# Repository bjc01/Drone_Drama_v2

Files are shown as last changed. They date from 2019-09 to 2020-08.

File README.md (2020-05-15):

# Drone_Drama_v2
DIY electronic musical Instrument

Drone & Drama v2 is a DIY synthesizer.

The complete unit contains the following:

3x sine / triangle function generators.

noise siren (a "bent by design" dub siren)

filter (a "bent by design" envelope filter)

4 channel mixer

The instrument is best suited to slow, drone and/or noise / music

Test commit

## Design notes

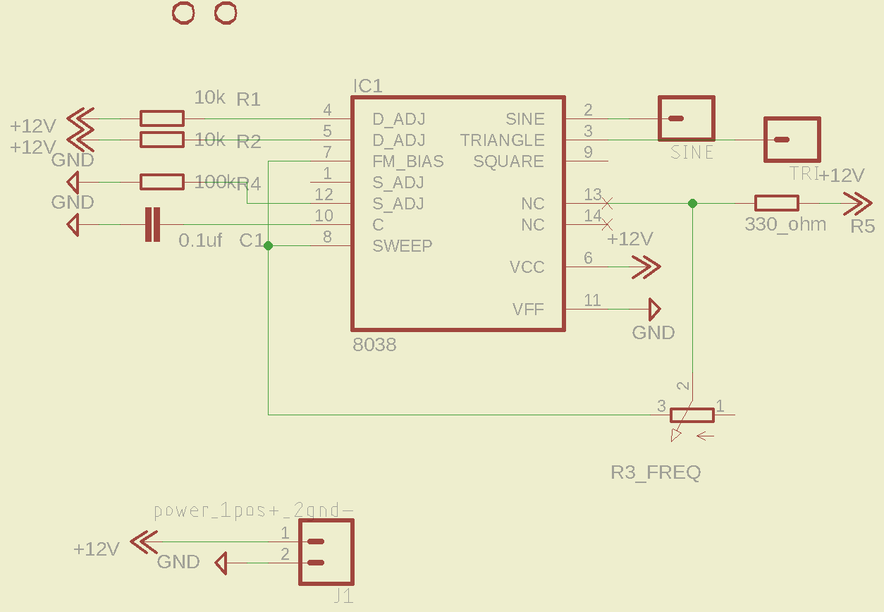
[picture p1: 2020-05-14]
D&Dv2 schematics/D&Dv2_sine_tri_12v.png

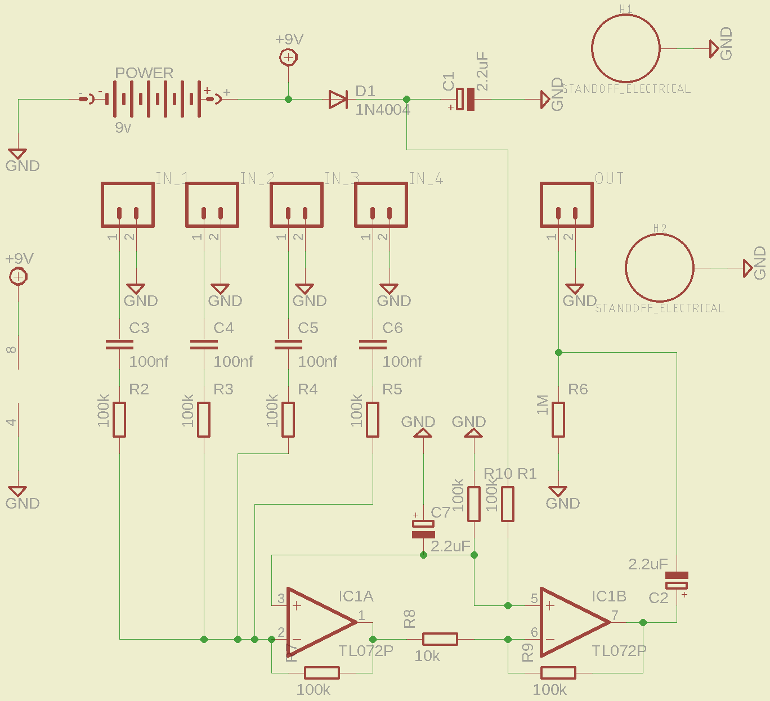
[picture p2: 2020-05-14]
D&Dv2 schematics/D&Dv2_4ch_mixer.png

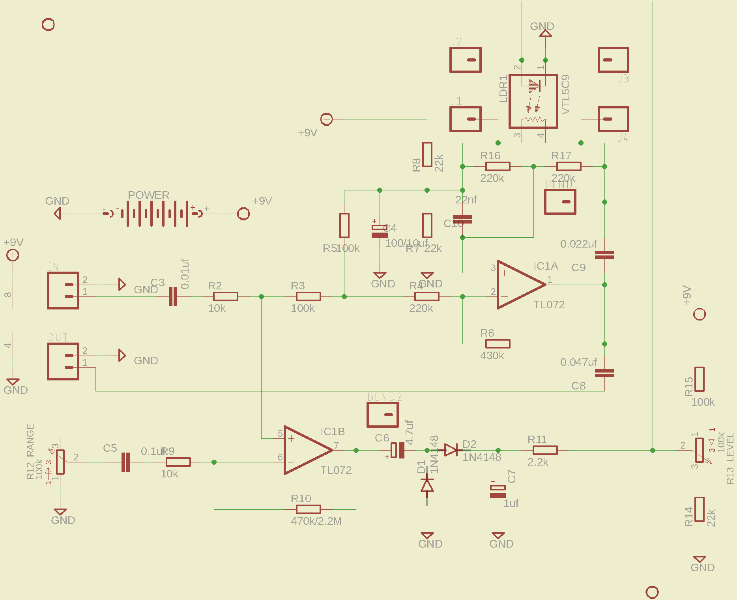
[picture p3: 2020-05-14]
D&Dv2 schematics/D&Dv2 filter.png

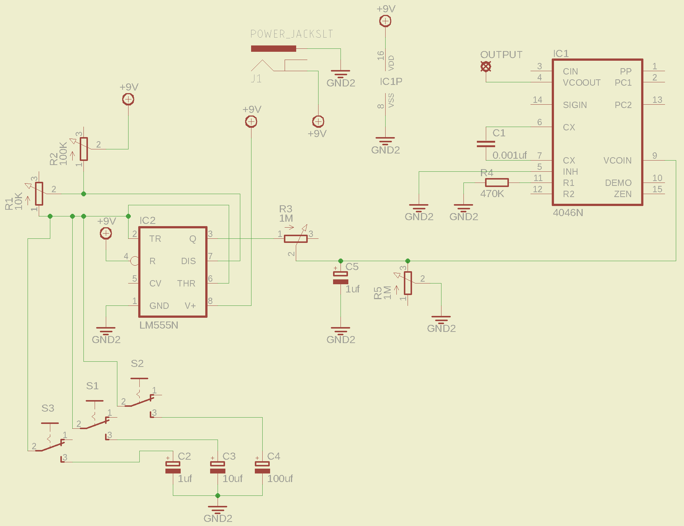
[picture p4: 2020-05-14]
D&Dv2 schematics/D&Dv2_noise_siren.png

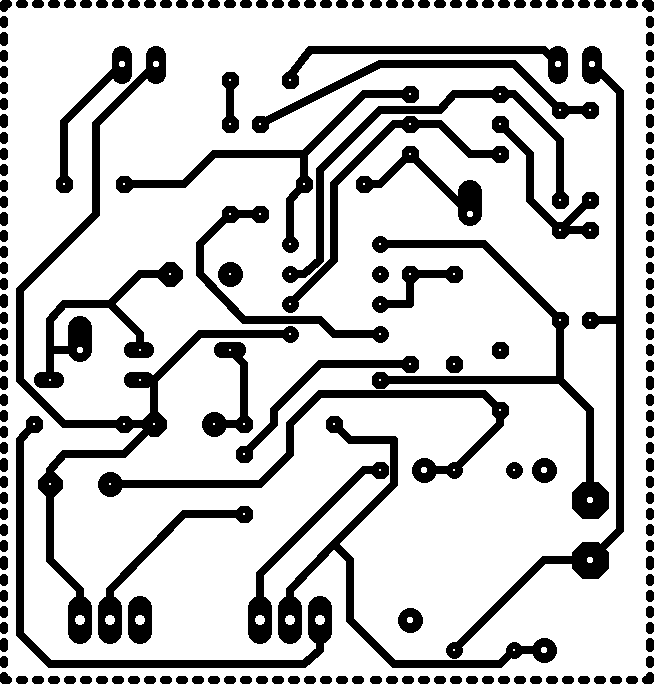
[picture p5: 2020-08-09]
D&Dv2 etch/filter etch top.png

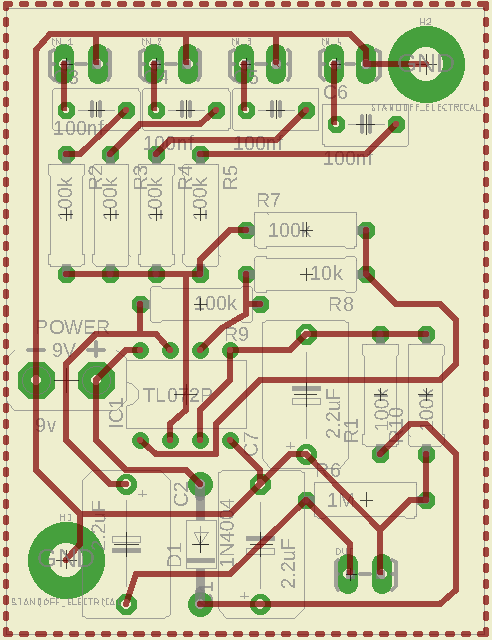
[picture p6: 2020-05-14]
D&Dv2 layout/D&Dv2_mixer_PCB1.png

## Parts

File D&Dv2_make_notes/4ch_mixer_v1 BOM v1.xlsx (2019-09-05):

4ch_mixer_v1 BOM
Part | Value | Device | Package | Description
C1 | 2.2uF | CPOL-EUB45181C | B45181C | POLARIZED CAPACITOR
C2 | 2.2uF | CPOL-EUB45181C | B45181C | POLARIZED CAPACITOR
C3 | 100nf | C-EU050-035X075 | C050-035X075 | CAPACITOR
C4 | 100nf | C-EU050-035X075 | C050-035X075 | CAPACITOR
C5 | 100nf | C-EU050-035X075 | C050-035X075 | CAPACITOR
C6 | 100nf | C-EU050-035X075 | C050-035X075 | CAPACITOR
C7 | 2.2uF | CPOL-EUB45181C | B45181C | POLARIZED CAPACITOR
D1 | 1N4004 | 1N4004 | DO41-10 | DIODE
IC1 | TL072P | TL072P | DIL08 | OP AMP
IN_1 | Audio input | CONN_02LOCK_LONGPADS | 1X02_LOCK_LONGPADS | Multi connection point. + / -
IN_2 | Audio input | CONN_02LOCK_LONGPADS | 1X02_LOCK_LONGPADS | Multi connection point. + / -
IN_3 | Audio input | CONN_02LOCK_LONGPADS | 1X02_LOCK_LONGPADS | Multi connection point. + / -
IN_4 | Audio input | CONN_02LOCK_LONGPADS | 1X02_LOCK_LONGPADS | Multi connection point. + / -
OUT | Audio output | CONN_02LOCK_LONGPADS | 1X02_LOCK_LONGPADS | Multi connection point. + / -
POWER | 12v power input +/- |  |  | 12v power input +/-
R1 | 100k | R-EU_0309/10 | 0309/10 | RESISTOR
R2 | 100k | R-EU_0309/10 | 0309/10 | RESISTOR
R3 | 100k | R-EU_0309/10 | 0309/10 | RESISTOR
R4 | 100k | R-EU_0309/10 | 0309/10 | RESISTOR
R5 | 100k | R-EU_0309/10 | 0309/10 | RESISTOR
R6 | 1M | R-EU_0309/10 | 0309/10 | RESISTOR
R7 | 100k | R-EU_0309/10 | 0309/10 | RESISTOR
R8 | 10k | R-EU_0309/10 | 0309/10 | RESISTOR
R9 | 100k | R-EU_0309/10 | 0309/10 | RESISTOR
R10 | 100k | R-EU_0309/10 | 0309/10 | RESISTOR
J1 | Audio output jack |  |  | 6.35mm mono output jack
use sockets for ICs!
Audio output jack EG: https://www.ebay.co.uk/itm/6-35mm-GUITAR-Jack-MONO-Socket-PCB-Mounting-Connections-Ends-AMP-Panel-Board-etc/392060661821

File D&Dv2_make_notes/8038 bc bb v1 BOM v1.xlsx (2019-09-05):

8038 bc bb v1 BOM
Part | Value | Device | Package | Description
C1 | 0.1uf |  |  | CAPACITOR - change this for change in frequency range
IC1 |  | ICL8038 | DIL14 | Precision WAVEFORM GENERATOR - https://www.ebay.co.uk/sch/i.html?_odkw=10-turn+pot+bournes+5k&_osacat=0&_from=R40&_nkw=icl8038&_sacat=0
J1 | 12v power pads +/- |  |  | 12v power pads +/-
R1 | 10k | R-EU_0204/5 | 0204/5 | RESISTOR
R2 | 10k | R-EU_0204/5 | 0204/5 | RESISTOR
R4 | 100k | R-EU_0204/5 | 0204/5 | RESISTOR
R5 | 330_ohm | R-EU_0204/5 | 0204/5 | RESISTOR
SINE | output pad | CONN_01PTH_LONGPAD | 1X01_LONGPAD | Sine wave output to toggle switch
TRI | output pad | CONN_01PTH_LONGPAD | 1X01_LONGPAD | Triangle wave output to toggle switch
R3 | 5k pot | frequency | 10-turn potentiometer | https://www.ebay.co.uk/sch/i.html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
Volume | 100k pot | volume | standard potentiometer | potentiometer 16mm / panel mount - https://www.ebay.co.uk/sch/i.html?_odkw=100k+pot&_osacat=0&_from=R40&_nkw=100k+pot+16mm&_sacat=0
Switch | SPDT toggle switch | waveform select sin/tri | two way / three pins | toggle switch - https://www.ebay.co.uk/sch/i.html?_odkw=icl8038&_osacat=0&_from=R40&_nkw=spdt&_sacat=0
Diode | zener diode | 1N4148 | standard diode | diode - https://www.ebay.co.uk/sch/i.html?_odkw=100k+pot+16mm&_osacat=0&_from=R40&_nkw=1n4148&_sacat=0
NB - for a full Drone & Drama v2 all of the above is needed three times - the above is for only enough to populate one drone PCB
use sockets for ICs!
A DC power socket (2.1mm panel mount wired tip negative) is useful to connect to a vero power board

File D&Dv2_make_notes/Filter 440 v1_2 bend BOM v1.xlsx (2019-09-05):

Filter 440 v1_2 bend BOM
Part | Value | Device | Package | Description
BEND1 | bend point | CONN_01OFFSET | 1X01_OFFSET | Single connection point.
BEND2 | bend point | CONN_01OFFSET | 1X01_OFFSET | Single connection point.
C3 | 0.01uf | C-EU050-035X075 | C050-035X075 | CAPACITOR
C4 | 100/10uf | CPOL-EUE5-6 | E5-6 | POLARIZED CAPACITOR, European symbol
C5 | 0.1uf | C-EU050-035X075 | C050-035X075 | CAPACITOR
C6 | 4.7uf | CPOL-EUE5-6 | E5-6 | POLARIZED CAPACITOR, European symbol
C7 | 1uf | CPOL-EUE5-6 | E5-6 | POLARIZED CAPACITOR, European symbol
C8 | 0.047uf | C-EU050-035X075 | C050-035X075 | CAPACITOR
C9 | 0.022uf | C-EU050-035X075 | C050-035X075 | CAPACITOR
C10 | 22nf | C-EU050-035X075 | C050-035X075 | CAPACITOR
D1 | 1N4148 | 1N4148DO35-7 | DO35-7 | DIODE
D2 | 1N4148 | 1N4148DO35-7 | DO35-7 | DIODE
IC1 | TL072 | TL072P | DIL08 | OP AMP
IN | Audio input | CONN_02LOCK_LONGPADS | 1X02_LOCK_LONGPADS | Multi connection point.
J1 | bend point | CONN_01 | 1X01 | Single connection point.
J2 | bend point | CONN_01 | 1X01 | Single connection point.
J3 | bend point | CONN_01 | 1X01 | Single connection point.
J4 | bend point | CONN_01 | 1X01 | Single connection point.
LDR1 | VTL5C9 | VTL5C9 | VTL5C | Axial Vactrols.
OUT | audio output | CONN_02LOCK_LONGPADS | 1X02_LOCK_LONGPADS | Multi connection point. Audio output +/-
POWER | 12v power +/- |  |  | 12v power +/-
R2 | 10k | R-EU_0207/7 | 0207/7 | RESISTOR
R3 | 100k | R-EU_0207/7 | 0207/7 | RESISTOR
R4 | 220k | R-EU_0207/7 | 0207/7 | RESISTOR
R5 | 100k | R-EU_0207/7 | 0207/7 | RESISTOR
R6 | 430k | R-EU_0207/7 | 0207/7 | RESISTOR
R7 | 22k | R-EU_0207/7 | 0207/7 | RESISTOR
R8 | 22k | R-EU_0207/7 | 0207/7 | RESISTOR
R9 | 10k | R-EU_0207/7 | 0207/7 | RESISTOR
R10 | 470k/2.2M | R-EU_0207/7 | 0207/7 | RESISTOR
R11 | 2.2k | R-EU_0207/7 | 0207/7 | RESISTOR
R12_RANGE | 100k | 308/309 | standard potentiomter | POTENTIOMETER
R13_LEVEL | 100k | 308/309 | standard potentiomter | POTENTIOMETER
R14 | 22k | R-EU_0207/7 | 0207/7 | RESISTOR
R15 | 100k | R-EU_0207/7 | 0207/7 | RESISTOR
R16 | 220k | R-EU_0207/7 | 0207/7 | RESISTOR
R17 | 220k | R-EU_0207/7 | 0207/7 | RESISTOR
Switch | SPDT toggle switcch | bend noise on/off | two way / three pins | toggle switch to connect bend points on PCB
Volume | A 100k |  | standard potentiomter | POTENTIOMETER
Power Starve | A 5k |  | standard potentiomter | POTENTIOMETER
NB - use sockets for ICs when possible!
DIY LDR+LED vactrol alternative: see stage 3 - https://www.instructables.com/id/Fizzle-Loop-Synth-V3/
toggle switch - https://www.ebay.co.uk/sch/i.html?_odkw=icl8038&_osacat=0&_from=R40&_nkw=spdt&_sacat=0

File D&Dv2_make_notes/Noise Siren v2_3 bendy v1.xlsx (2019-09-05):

Noise Siren v2_3 bendy
Part | Value | Device | Package | Description
C1 | 10uF | CPOL-EUB45181B | B45181B | POLARIZED CAPACITOR
C2 | 1uF | CPOL-EUB45181B | B45181B | POLARIZED CAPACITOR
C3 | 0.001uF | CPOL-EUB45181B | B45181B | POLARIZED CAPACITOR
C4 | 100uF | CPOL-EUB45181B | B45181B | POLARIZED CAPACITOR
G1 | 12v power + / - |  |  | 12v power + / -
IC1 | 555 | 555P | DIP08 | General purpose bipolar Timer
IC2 | 4046N | 4046N | DIL16 | Micropower PLL - phase locked loop
OUTPUT | Audio output to filter input | CONN_02LOCK_LONGPADS | 1X02_LOCK_LONGPADS | Multi connection point. Audio + / -
R1 | 1M | R-EU_0207/10 | 0207/10 | RESISTOR
R2 | 1M | R-EU_0207/10 | 0207/10 | RESISTOR
R3 | 470k | R-EU_0207/10 | 0207/10 | RESISTOR
S1 | SPDT toggle switch | M9040P | two position / three pin | TOGGLE SWITCH
S2 | SPDT toggle switch | M9040P | two position / three pin | TOGGLE SWITCH
S3 | SPDT toggle switch | M9040P | two position / three pin | TOGGLE SWITCH
VR1 | 100k | POTENTIOMETER-PTH-9MM-1/20W-20%-KIT | POT-PTH-ALPS-KIT | Potentiometer (Pot)
VR2 | 10k | POTENTIOMETER-PTH-9MM-1/20W-20%-KIT | POT-PTH-ALPS-KIT | Potentiometer (Pot)
VR3 | 10k | POTENTIOMETER-PTH-9MM-1/20W-20%-KIT | POT-PTH-ALPS-KIT | Potentiometer (Pot)
VR4 | 1k | POTENTIOMETER-PTH-9MM-1/20W-20%-KIT | POT-PTH-ALPS-KIT | Potentiometer (Pot)
bends | 6pcs banan jacks | banana jacks |  | 6 pieces - Banana jacks for bend points
NB - use sockets for ICs when possible!

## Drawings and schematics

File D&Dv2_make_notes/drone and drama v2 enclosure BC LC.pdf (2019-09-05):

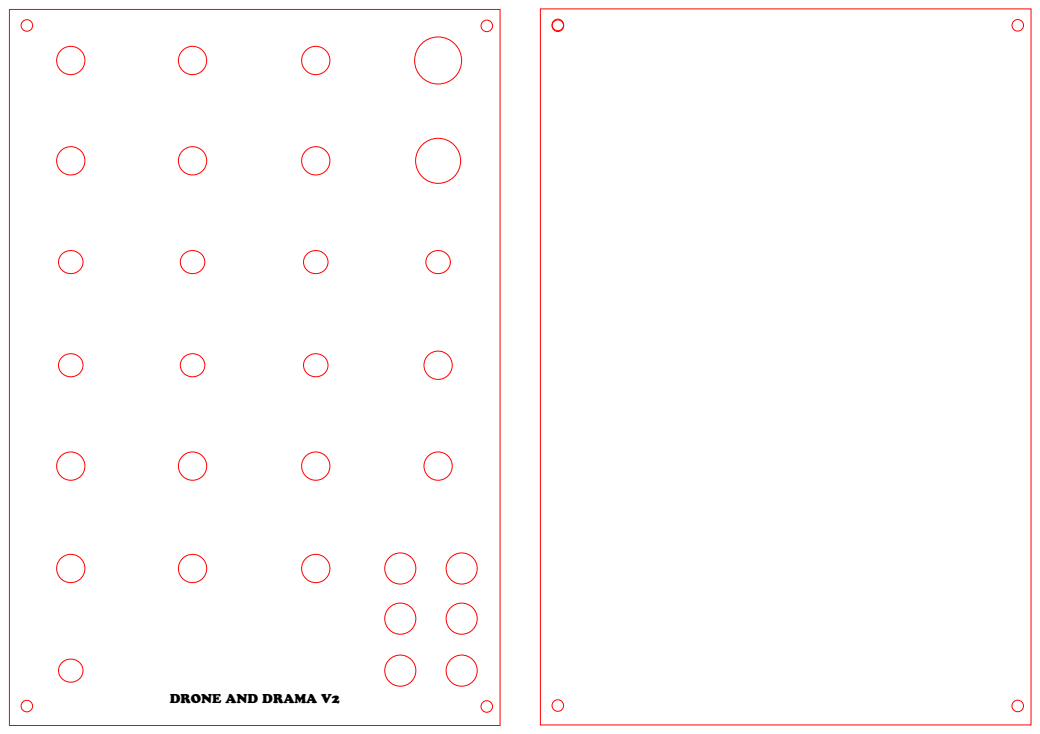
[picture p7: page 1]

DRONE AND DRAMA V2

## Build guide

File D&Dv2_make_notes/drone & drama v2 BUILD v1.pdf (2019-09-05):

Drone & Drama v2
Build document

The instrument is made of several boards. See the diagrams for component placement. Note the pad markings for power, audio input and output and potentiometer or switch connections. Some of the pads have symbols (+/-) to represent positive or ground/negative connections.
With each PCB begin with the smallest (lowest profile) components and work up to the largest:
Resistors & diodes / Capacitors / IC socket & IC / Vactrol / Connecting wire.

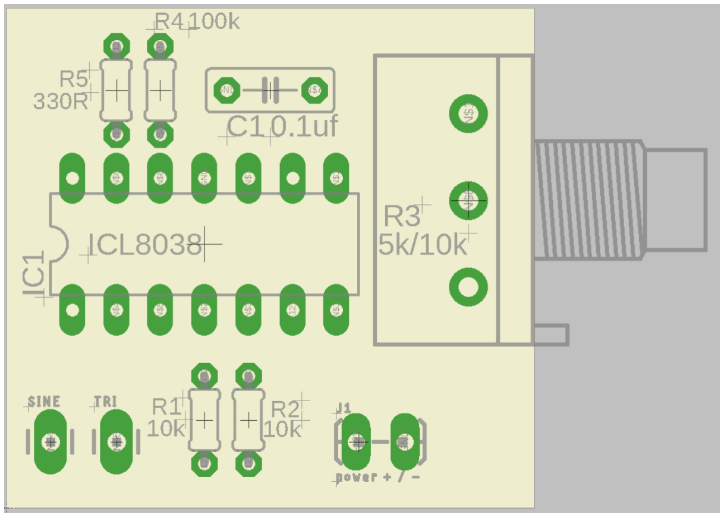
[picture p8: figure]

8038 Function Generator v1_1
The SINE & TRI pads should be connected to the outer lugs (1 & 3) of a three pin SPDT toggle switch.
The centre lug of the toggle switch (2) should be connected to the outer lug (3) of the volume pot using a 1N4148 diode. Negative towards the pot.

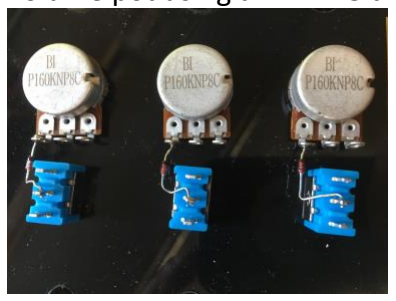
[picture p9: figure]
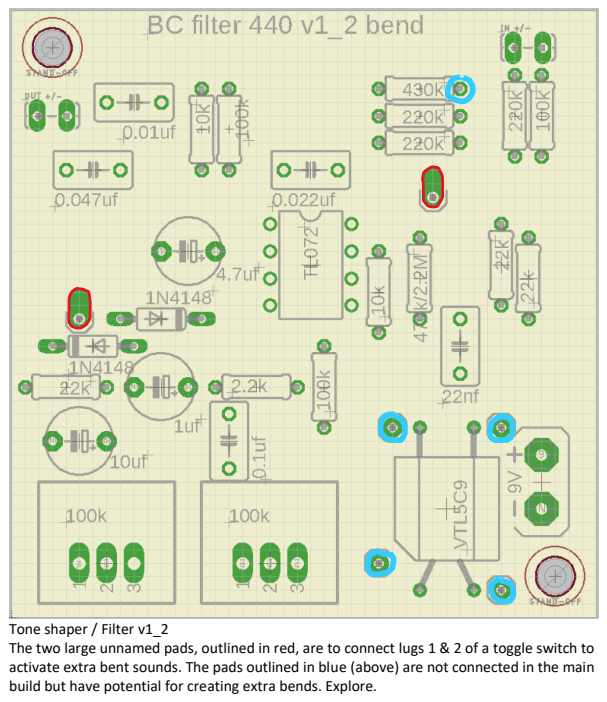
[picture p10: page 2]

Tone shaper / Filter v1_2
The two large unnamed pads, outlined in red, are to connect lugs 1 & 2 of a toggle switch to
activate extra bent sounds. The pads outlined in blue (above) are not connected in the main
build but have potential for creating extra bends. Explore.

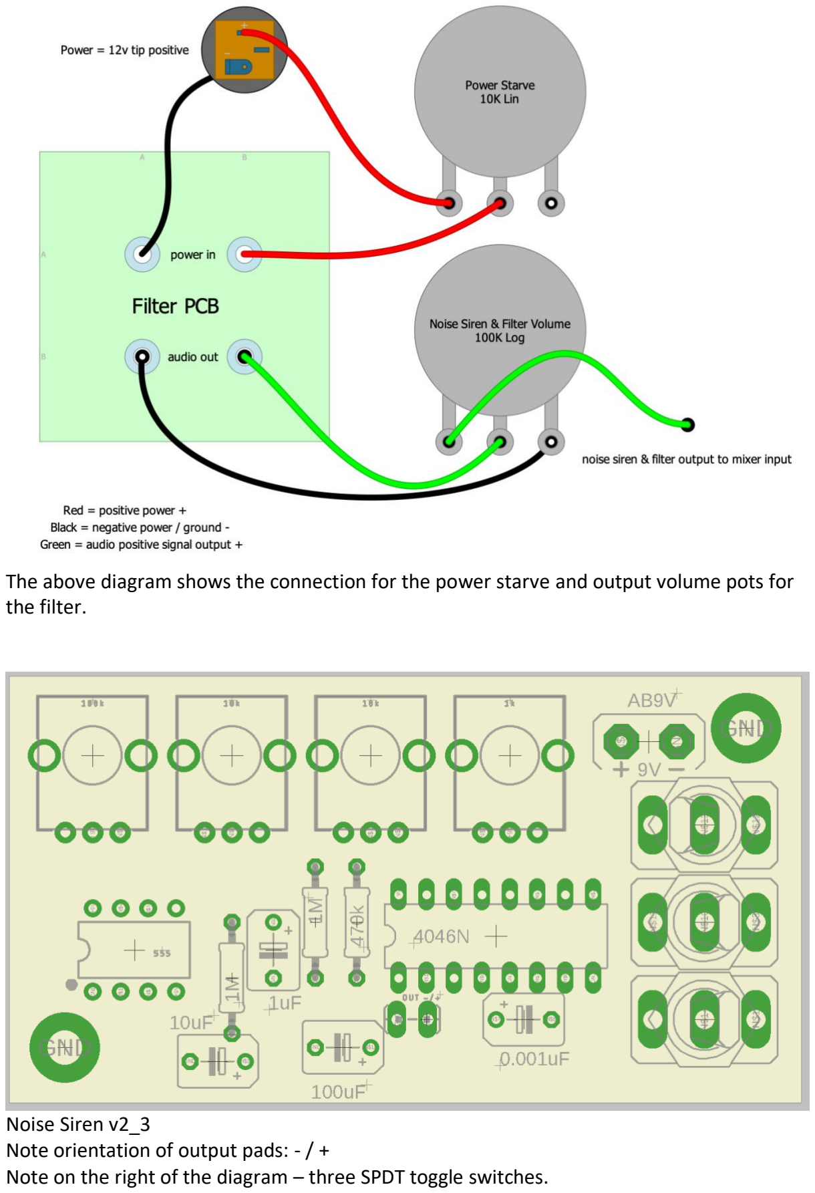
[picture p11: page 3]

The above diagram shows the connection for the power starve and output volume pots for the filter.

Noise Siren v2_3
Note orientation of output pads: - / +
Note on the right of the diagram – three SPDT toggle switches.

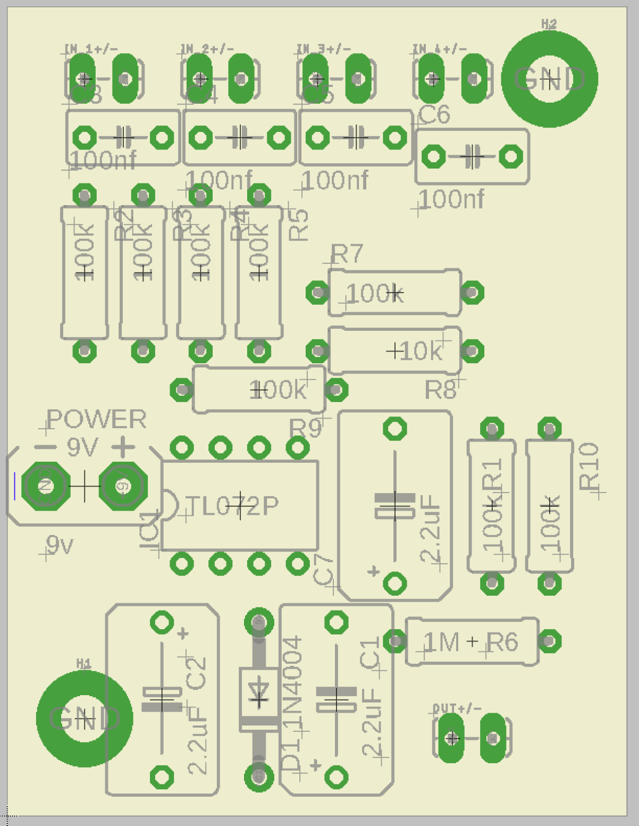
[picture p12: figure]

4 Channel Mixer v1

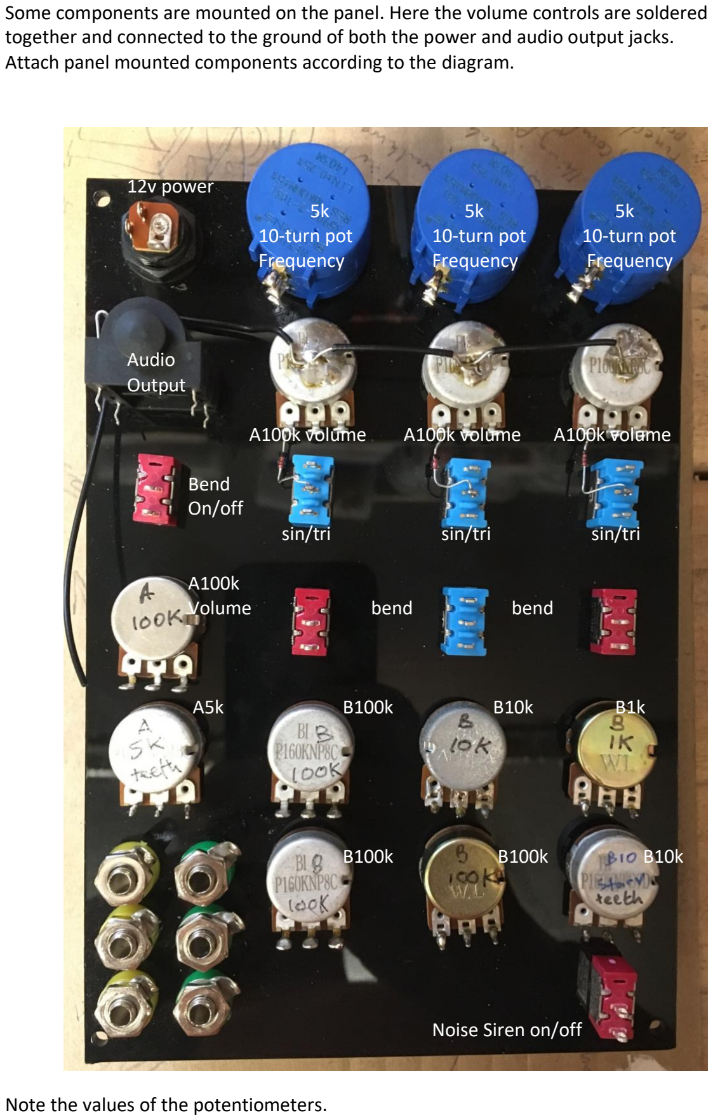
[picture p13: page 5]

Some components are mounted on the panel. Here the volume controls are soldered together and connected to the ground of both the power and audio output jacks. Attach panel mounted components according to the diagram.

12v power
5k | 5k | 5k
10-turn pot | 10-turn pot | 10-turn pot
Frequency | Frequency | Frequency

Audio
Output
A100k volume | A100k volume | A100k volume

Bend
On/off
sin/tri | sin/tri | sin/tri

A100k
Volume | bend | bend
A5k | B100k | B10k | B1k
B100k | B100k | B10k

Noise Siren on/off

Note the values of the potentiometers.

Quite a number of connecting wires are required to connect the PCBs.

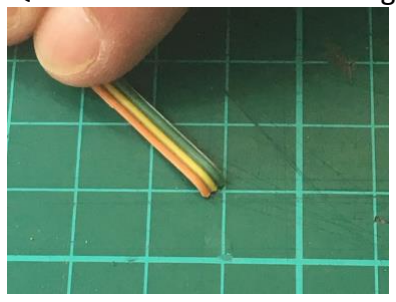
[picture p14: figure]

Rainbow coloured ‘ribbon’ cable can be very useful.

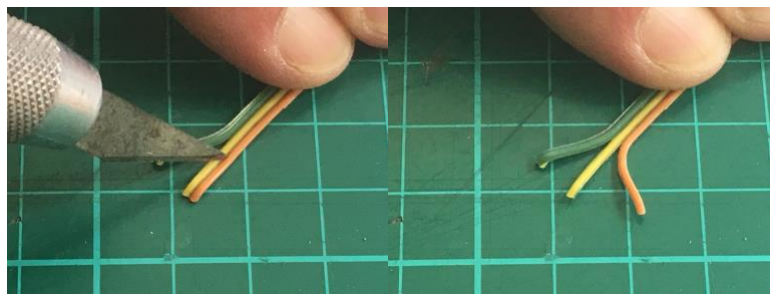
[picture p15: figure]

Make two-centimetre-long cuts between the strands. Separate the number of strands required.

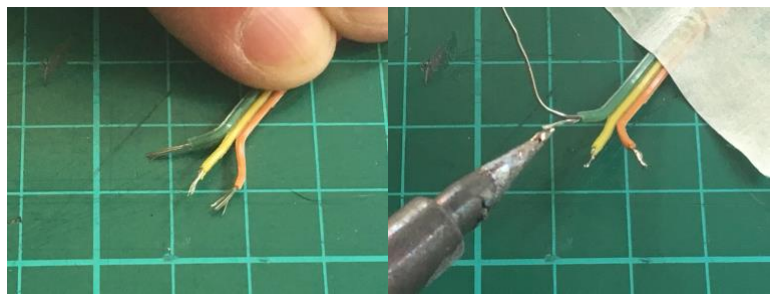
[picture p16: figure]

Strip away the plastic shield.
Tin the wires.
Tinning is melting a small amount of solder to a wire or component as a way of preparing it to be joined to another part.

Populate all the PCBs with the components as per the diagrams above.
Then prepare connecting wires to join the modules to one another and the interface hardware.

Here are suggested lengths and quantities to prepare wires for the main boards :
Connection | Wire length (cm) | Quantity
Power to drone | 10 | 1
Power to mixer | 18 | 1
Power to filter | 18 | 1
Power to noise siren | 20 | 1
Drone to mixer | 8 | 3
Mixer to output | 18 | 1
Noise to filter | 20 | 1
Noise to banana jacks | 10 | 2
Filter to mixer | 20 | 1

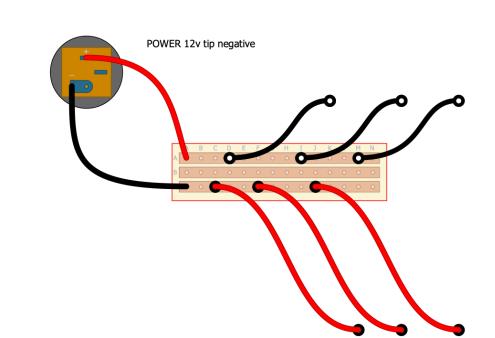
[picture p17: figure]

In order to make connecting each PCB to the power socket a little easier, I added a small section of vero board with a positive and negative/ground strip as per the illustration above.

When all of the PCBs are attached to their control hardware and one another, there is one more step. Connect the following pins of the CD4049 ic of the Noise Siren to the six banana jack sockets. See below the standard version with the wires soldered to the bottom of the PCB.

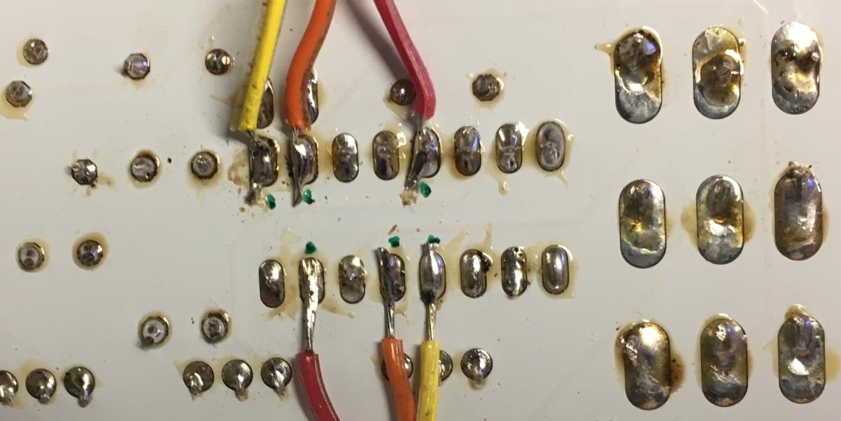
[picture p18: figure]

A panel, faceplate or enclosure for the controls is needed along with wire to connect the parts. An SVG or PDF file to laser cut two Perspex plates to form a ‘sandwich’ style enclosure can be downloaded from github/here.

Please ensure that the stroke width of the lines is set to the correct width to ensure clean cuts and engraving as per the laser machine you use.

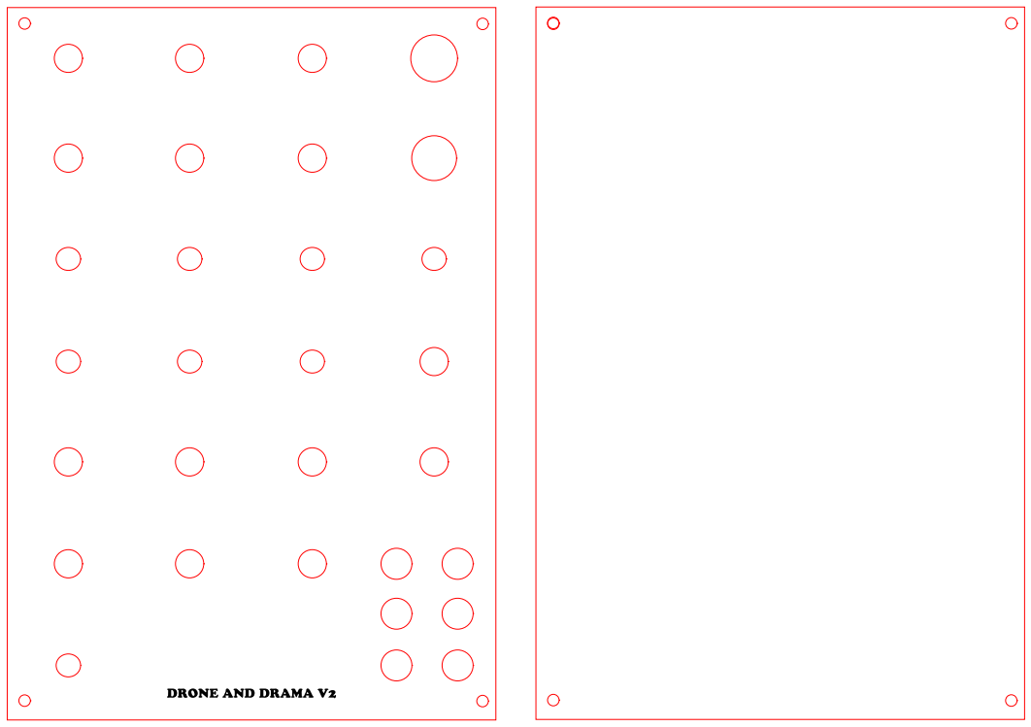
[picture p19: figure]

Drone & Drama v2 top and bottom plates to create ‘sandwich’ enclosure. The top and bottom plates are held together using hex standoffs. There should be around 3.5cm clearance between the two plates to ensure there is ample space for the interface hardware, connecting wires and PCBs.

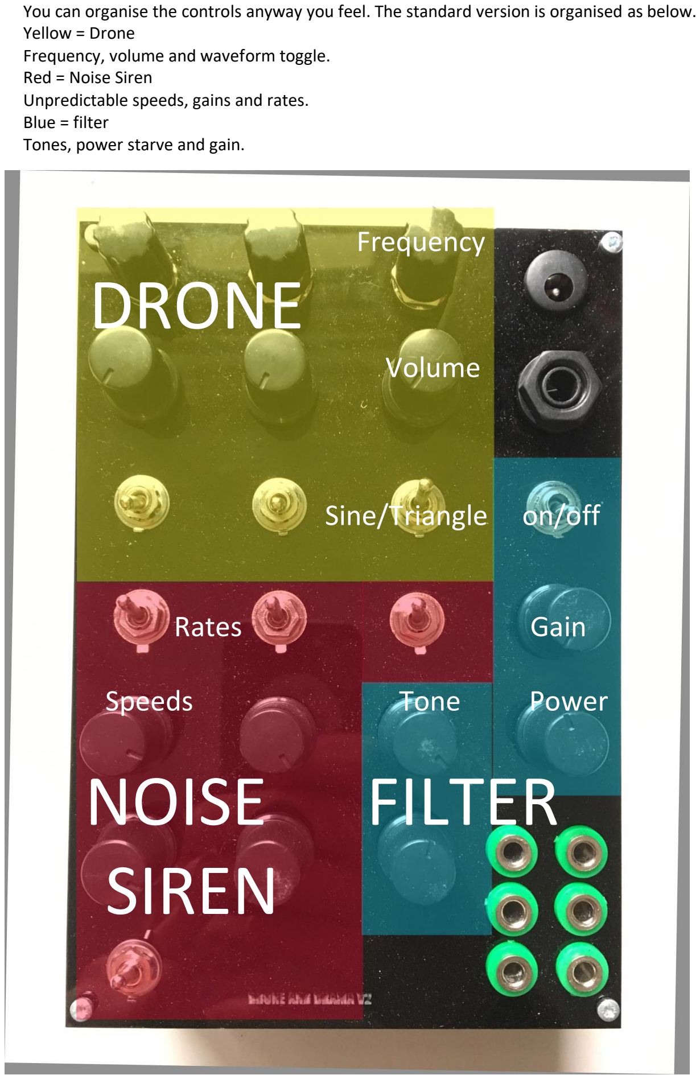
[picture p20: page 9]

You can organise the controls anyway you feel. The standard version is organised as below. Yellow = Drone
Frequency, volume and waveform toggle.
Red = Noise Siren
Unpredictable speeds, gains and rates. Blue = filter
Tones, power starve and gain.

## Frequency

# DRONE

## Volume

## Sine/Triangle on/off

Rates | | Gain
Speeds | Tone | Power
NOISE | FILTER

# SIREN

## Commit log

2019-09-05 Adding XLS files.
    [4ch_mixer_v1 BOM v1.xlsx, 8038 bc bb v1 BOM v1.xlsx, Filter 440 v1_2 bend BOM v1.xlsx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]
2019-09-05 added laser pdf
2020-05-14 Add files via upload
    Schematics
2020-05-14 Add files via upload
    Gerber files to create PCBs
    [copper_bottom.gbr, copper_top.gbr, drills.xln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]
